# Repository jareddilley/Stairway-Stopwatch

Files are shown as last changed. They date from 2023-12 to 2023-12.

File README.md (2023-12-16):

# Stairway-Stopwatch

Racing up and down the stairs used to be just for kids, not anymore. As the holidays approach, I have created a stopwatch so you can turn racing up and down the stairs into a sport. The 3D printed system uses RF communication and motion sensing for ease of use. This would be a great build for you and your roommates or even your kids. This creation has a YouTube video as well so those who are visual learners can be entertained (https://youtu.be/VbG-spBBNq0). Below are the schematics for both the receiver and transmitter:

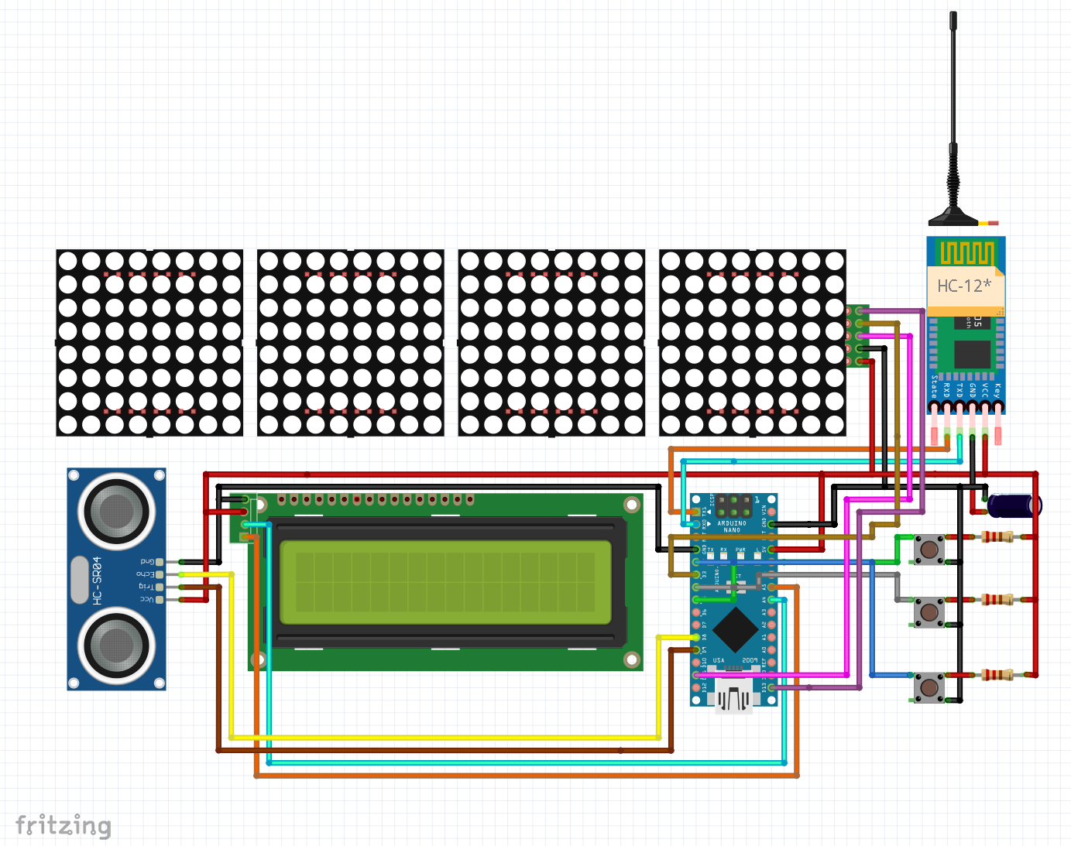
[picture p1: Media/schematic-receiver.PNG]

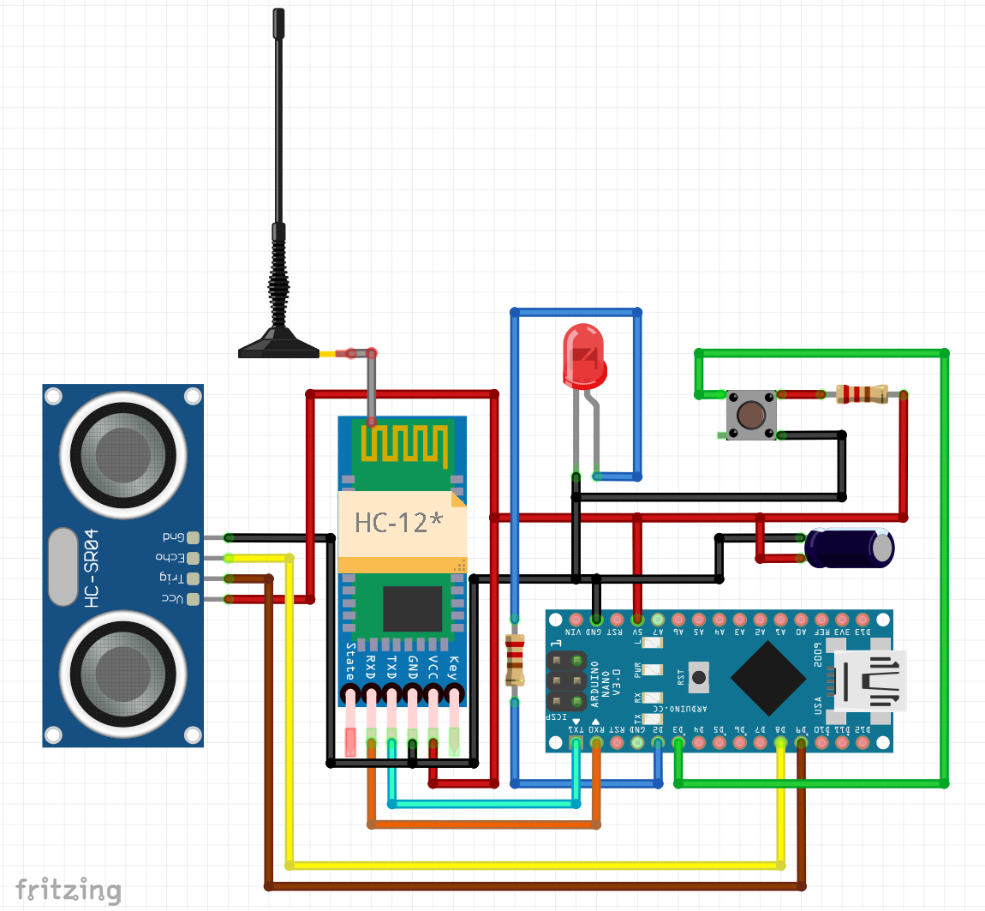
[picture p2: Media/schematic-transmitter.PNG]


# Displays


The main stopwatch display is a MAX7219 Dot Matrix Module for Arduino Microcontroller 4-in-1 Display. It comes in a red and green variety. The display is updated easily by simply sending a string value to the display. The default font did not fit neatly in the full display so I used a Font.h file to alter the font of the displayed numbers. For the best time tracker, I used an I2C Serial LCD Module 16x2 Display. This display uses a cursor to display the values so when updating I have to redraw all the letters. 

# Wireless Communication


The wireless communication took some troubleshooting. I tried the 315Mhz RF Transmitter and Receiver Modules but the range was not enough to reach up to 3 stories and is only one-way transmission. I also tried the NRF24L01+ 2.4GHz Arduino Wireless RF Transceiver but I could not get it to properly work with my Arduino boards. Luckily I was able to land on a solution, the HC-12 433Mhz SI4438 Wireless Serial Port Module. This module says it can do up to 1000 meters, way beyond my needs. It has a simple pin layout to reduce wires and uses simple serial print and read functions to communicate back and forth. 

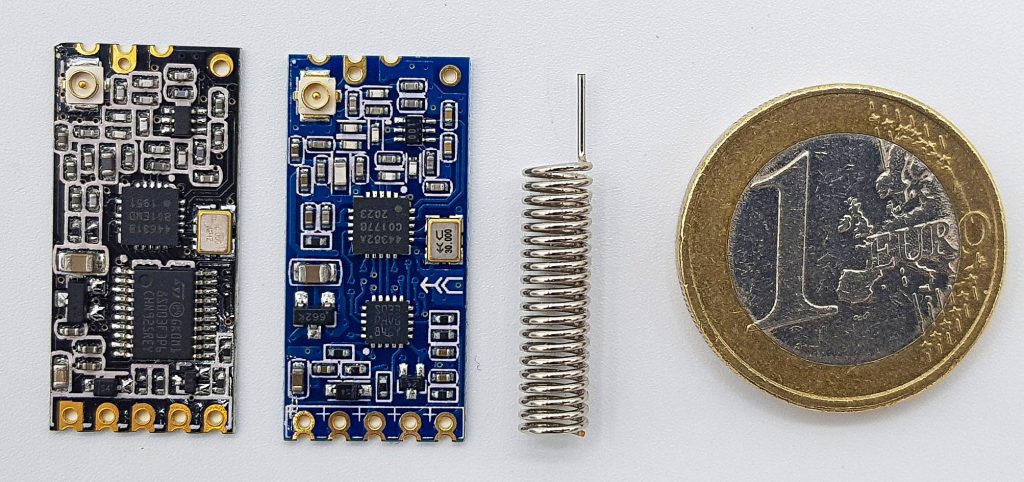
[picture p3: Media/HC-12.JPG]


# Motion sensing


For ease of use, I went with ultrasonic sensors for motion sensing. The transmitter has a ready-up button with a 2-second delay so that the stopwatch does not start by accident or start every time you walk in from the garage. The transmitter had issues with noise in the data so I went with a moving average to remove the noise. The moving average simply takes every 5 data points and averages them so that the sensor does not just trip on a single value.

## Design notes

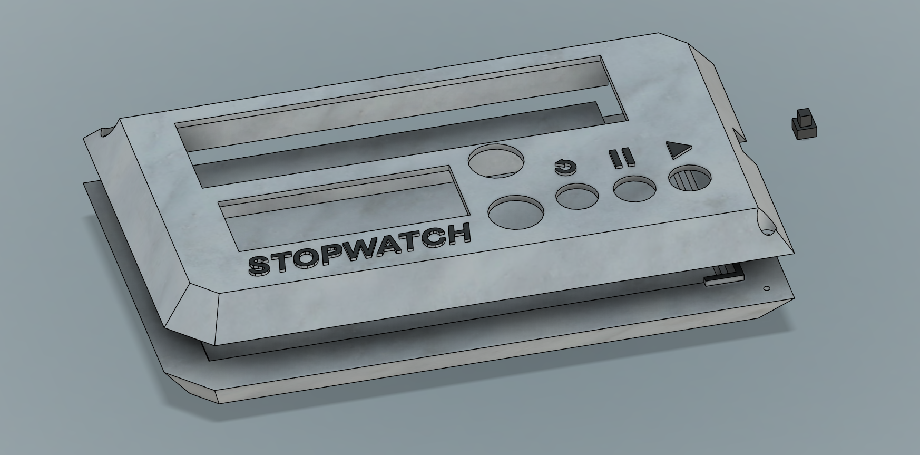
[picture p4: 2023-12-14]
Media/F360-receiver.PNG

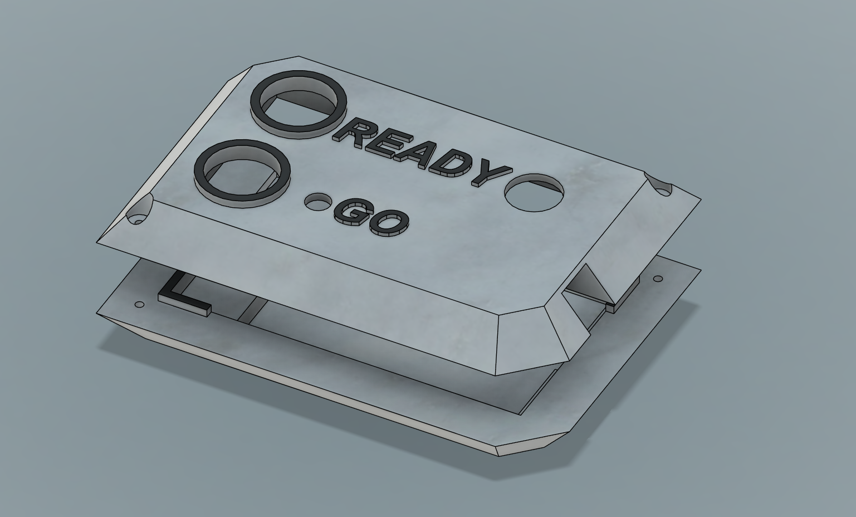
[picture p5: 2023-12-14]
Media/F360-transmitter.PNG

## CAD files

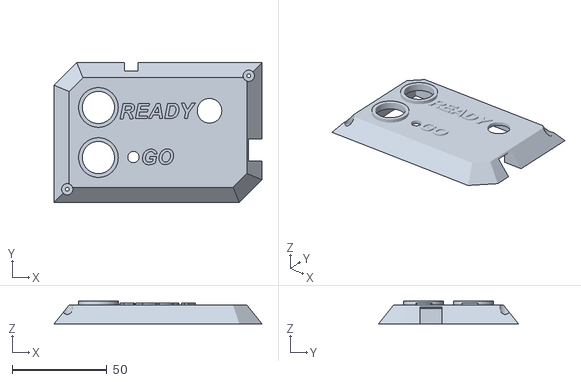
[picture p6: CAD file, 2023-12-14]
STL files/TOP_transmitter.stl
110.0 x 74.0 x 12.0

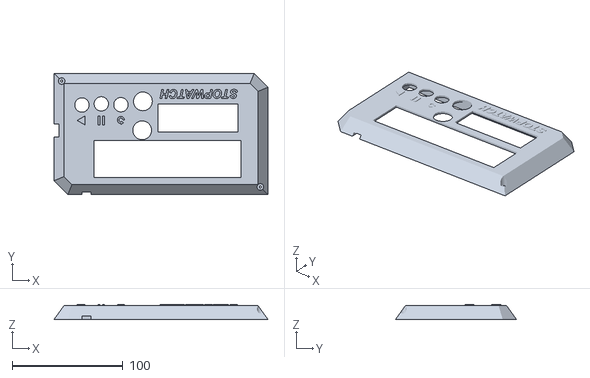
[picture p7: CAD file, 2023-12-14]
STL files/TOP_receiver.stl
193.5 x 109.5 x 13.5

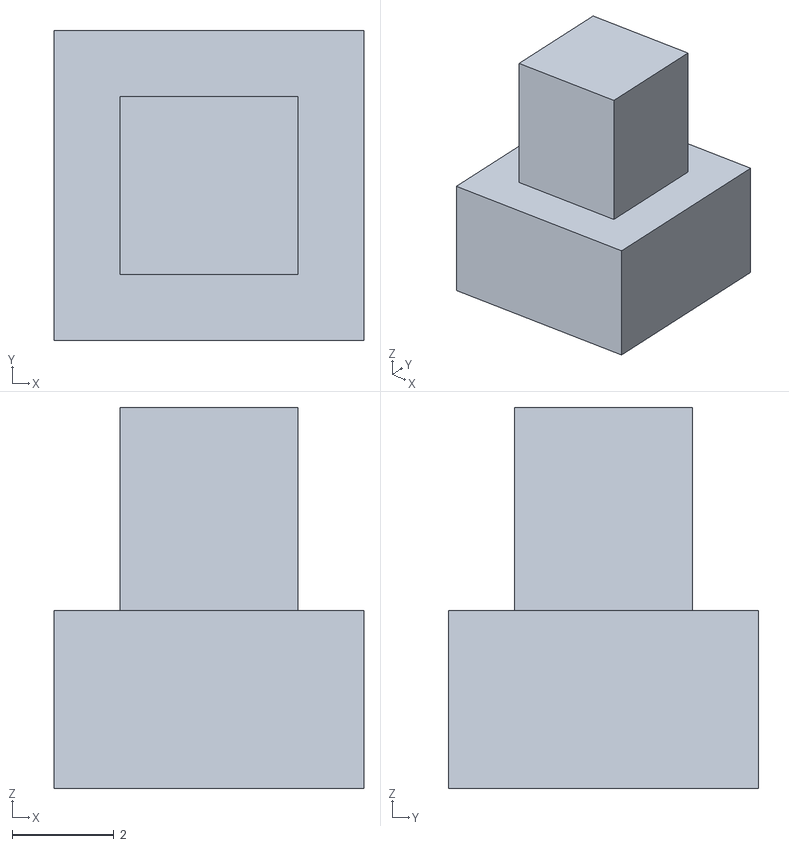
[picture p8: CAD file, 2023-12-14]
STL files/Button_offset.stl
6.10 x 6.10 x 7.50

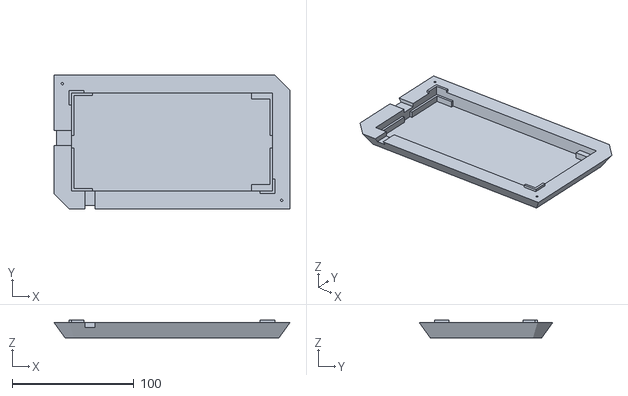
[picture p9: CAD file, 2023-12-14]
STL files/BASE_receiver.stl
193.5 x 109.5 x 14.5

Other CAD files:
STL files/BASE_transmitter.stl
Fusion 360/stopwatch_receiver.f3d
Fusion 360/stopwatch_transmitter.f3d

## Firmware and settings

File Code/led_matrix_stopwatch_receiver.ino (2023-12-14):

#include <LiquidCrystal_I2C.h>
#include <MD_Parola.h>
#include <MD_MAX72xx.h>
#include <SoftwareSerial.h>
#include <SPI.h>

#include "Font_Data.h"

#define HARDWARE_TYPE MD_MAX72XX::FC16_HW
#define MAX_DEVICES 4
#define CS_PIN 3

#define SPEED_TIME  75
#define PAUSE_TIME  0
#define MAX_MESG  20

int brightness = 1;

const int trigPin = 8;
const int echoPin = 9;
long duration = 0;
int distance = 100;
     
int count = 0;
int m=0;     
int s=0;     
int ms=0;   
int total = 0;
int best = 0;
const int startPin = 5;    
const  int stopPin = 4;    
const int resetPin = 2; 
char szMinSec[9];    // mm:ss\0
char szMillisec[4];  // ms
char bestTime[14];   // mm:ss:ms
bool f = true;       // blinker for :
bool manual = false;

MD_Parola myDisplay = MD_Parola(HARDWARE_TYPE, CS_PIN, MAX_DEVICES);

LiquidCrystal_I2C lcd(0x27,16,2);
SoftwareSerial HC12(0, 1); // TX, RX

/*
Updates the LED matix display
*/
void updateDisplay()
{
  sprintf(szMinSec, "%02d%c%02d", m, (f ? ':' : ' '), s);
  sprintf(szMillisec, "%02d", ms); 
  sprintf(bestTime, "%02d:%02d:%02d", m,s,ms);
  myDisplay.displayAnimate();
  myDisplay.displayReset(0);
  myDisplay.displayReset(1); 

  return;
}

/*
Updates the TIME TO BEAT display
*/
void updateBestTime()
{ 
  lcd.clear();   
  lcd.setCursor(2,0);  
  lcd.print("TIME TO BEAT"); 
  lcd.setCursor(4,1); 
  lcd.print(bestTime);

  return;
}

/*
Main Stopwatch increment loop
*/
void stopwatch()
{
  ms++;
  total++;

  if(ms==100)   // sec increment       
  {
    ms=0,s++; 
  }
  if(ms%50 == 0)   // : ticker      
  {
    f=!f;
  }
  if(s==60)     // min increment
  { 
    s=0,m++; 
  }

  updateDisplay();

  // utrasonic sensor measurement 
  digitalWrite(trigPin, LOW);
  delayMicroseconds(2);
  digitalWrite(trigPin, HIGH);
  delayMicroseconds(10);  
  digitalWrite(trigPin, LOW);
  duration += pulseIn(echoPin, HIGH);
  count++;
  distance = 100;

  if(count == 4){ // moving average
    distance = (duration * 0.034 / (2 * 4));
    count = 0;
    duration = 0;
  }

  if((digitalRead(stopPin) == LOW) || (distance < 50 && !manual))    // stop button or motion sensor tripped
  {
    f=true;
    if((total < best || best==0 ) && total > 60)
    {
      best = total;
      updateBestTime();
    }
    manual = false;
    stopwatch_stop();
  } 
  else if (digitalRead(resetPin) == LOW)  // reset button
  {
    stopwatch_reset();
    loop();
  }
  else{
    stopwatch(); 
  }
}

/*
Stopwatch stopped loop
*/
void stopwatch_stop()
{
  updateDisplay();
  
  
  if (digitalRead(startPin) == LOW) // start button
  {
    manual = true;
    stopwatch(); 
  } 
  if(digitalRead(resetPin) == LOW)  // reset button
  {
    stopwatch_reset();  
    loop();
  } 
  if(HC12.available()){ // start rf signal recieved 
    int input = HC12.read();
    if(input == '1'){ 
      stopwatch_reset();
      stopwatch();
    }
  }
  stopwatch_stop();
}

/*
Reset stopwatch and displays
*/
void stopwatch_reset()
{
  m=0;
  s=0;
  ms=0;
  total = 0;
  count = 0;
  duration = 0;
  distance = 100;
  manual = false;
  f = true;
  
  updateDisplay();

  return;
}

void setup() {
  myDisplay.begin(3);

  // Set up the two zones for LEd matrix
  myDisplay.setZone(0, 0, 0);   // Zone 0 - ms
  myDisplay.setZone(1, 1, 3);   // Zone 1 - min : sec
  myDisplay.setFont(0, numeric7Seg);  // smaller font for ms
  myDisplay.setFont(1, numeric7Se);
  myDisplay.displayZoneText(0, szMillisec, PA_LEFT, SPEED_TIME, 0, PA_PRINT, PA_NO_EFFECT);
  myDisplay.displayZoneText(1, szMinSec, PA_CENTER, SPEED_TIME, PAUSE_TIME, PA_PRINT, PA_NO_EFFECT);
  
  // Change brightness (0-15)
  myDisplay.setIntensity(brightness);

  sprintf(szMinSec, "%02d%c%02d", m, (f ? ':' : ' '), s);
  sprintf(szMillisec, "%02d", ms);
  sprintf(bestTime, "%02d:%02d:%02d", m,s,ms);

  pinMode(trigPin, OUTPUT);
  pinMode(echoPin, INPUT); 
  pinMode(startPin, INPUT);
  pinMode(stopPin, INPUT);
  pinMode(resetPin, INPUT);

  // Init TIME TO BEAT display
  lcd.init();
  lcd.backlight(); 
  updateBestTime();

  HC12.begin(9600);
}

void loop() {
  myDisplay.displayAnimate();
  myDisplay.displayReset(0);
  myDisplay.displayReset(1);
  
  if(HC12.available()){ // start rf signal recieved 
    int input = HC12.read();
    if(input == '1'){ 
      stopwatch();
    } 
  } 
  if(digitalRead(startPin) == LOW){  // start button
    manual = true;
    stopwatch();
  }

  //HC12.flush();
  //delay(20);
}

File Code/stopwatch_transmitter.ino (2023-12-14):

#include <SoftwareSerial.h>

#define trigPin 9
#define echoPin 8
#define Button 3
#define LED 2

long duration;
int distance;
bool ready = false;

SoftwareSerial HC12(1, 0); // TX, RX

void setup() {
  pinMode(trigPin, OUTPUT);
  pinMode(Button, INPUT);
  pinMode(echoPin, INPUT);
  pinMode(LED, OUTPUT);

  HC12.begin(9600);
}

void loop() {
  if (digitalRead(Button) == LOW){
    digitalWrite(LED, HIGH); // turn on ready LED
    ready = true;
    delay(2000); //safety delay
  }
  
  while(ready) // ready button clicked
  {
    // Reads the echoPin, returns the sound wave travel time in microseconds
    duration = 0;
    delayMicroseconds(5);
    digitalWrite(trigPin, HIGH);
    delayMicroseconds(5);  
    digitalWrite(trigPin, LOW);
    duration += pulseIn(echoPin, HIGH);
    distance = (duration * 0.034 / 2);

    if (distance < 50) // motion sensor tripped
    {
      HC12.print('1');
      delay(20);
      digitalWrite(LED, LOW);
      ready = false;
    }
  }
}
